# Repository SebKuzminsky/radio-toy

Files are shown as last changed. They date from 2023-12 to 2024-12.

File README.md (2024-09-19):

This is a project inspired by the [Flipper
Zero](https://flipperzero.one/) and the
[ook-remote](https://github.com/SebKuzminsky/ook-remote/tree/master).

The goal is to identify, record, & spoof RF remotes (like the WEN3410
air filter at the hack space).

# Design thoughts

## Radio chip

* [CC1101](https://www.ti.com/product/CC1101).  Lots of modules available.
I have a D-Sun CC1101 and an Ebyte E07-M1101D, they seem about equivalent.
SMA connector, 2x5 male pin header, 2 mounting holes near the antenna.
The D-SUN mounting holes are slightly more convenient.  There's also one
called AS07-M1101S.  For building into a portable product, a module with
solderable through holes instead of the pin header may be preferable.

* [Semtech Sx1276](https://www.semtech.com/products/wireless-rf/lora-connect/sx1276)

* [nRF24L01](https://www.nordicsemi.com/Products/nRF24-series)
"Not recommended for new designs", but it's hard to argue with $1 boards from ebay.
<https://www.sparkfun.com/datasheets/Components/SMD/nRF24L01Pluss_Preliminary_Product_Specification_v1_0.pdf>

## Tethered or untethered?

### Tethered

Connect by USB-C to a laptop or an Android phone (serial terminal or
custom app).

Pros:
* simple to build (no battery & charging)
* simple to talk to (minicom or pySerial)

Cons:
* Conspicuous to have a dongle out and connected.

### Untethered

LiPo battery & USB charging.

LiPo battery options:
* 1x18650: 2200 mAh, 19 mm x 68 mm
* 2x18650: 4400 mAh, 38 mm x 66 mm
* Adafruit Feather battery: 400 mAh, 17.5 mm x 37 mm (fits under a Feather or Pico)

Cons:
* battery & charger
* Bulkier

#### Web UI

The device is a featureless brick, like a USB "power bank".  It has a
USB port (for charging the battery) and an on/off switch.

You connect by Bluetooth or Wifi to a UI on a laptop or phone.  This is
very inconspicuous - you can leave the device in a pocket or backpack
and just play with your phone or laptop.

Or web UI over IP-over-USB,
e.g. <https://github.com/maxnet/pico-webserver>?

I don't know of an RP2040 board with both LiPo and Wifi.  I could
use a Pico W and and external LiPo charger/power supply like this one:
* <https://www.adafruit.com/product/5612>
* <https://shop.pimoroni.com/products/pico-lipo-shim>

BOM:
* Pico W (21 mm wide, 51 mm long)
* CC1101 module of some sort (FIXME)
* Pimoroni Pico LiPo Power Shim (fits under Pico W, solders onto its headers)
* LiPo battery
* 3d printed case

RP2040 board options:
* Pico W
* Seeed Wio RP2040 <https://www.seeedstudio.com/Wio-RP2040-mini-Dev-Board-p-4933.html>
* Arduino Nano RP2040 Connect

# Wiring

```
    Pico GPIO          | Pico Pin | D-Sun CC1101 module
    -------------------+----------+--------------------
    3V3 Out            | 36       | VCC
    GND                | 38       | GND
    -------------------+----------+--------------------
    GPIO 2 (SPI0 SCK)  | 4        | SCK
    GPIO 3 (SPI0 TX)   | 5        | MOSI
                       |          | GDO2
    GPIO 4 (SPI0 RX)   | 6        | MISO
    GPIO 1 (SPI0 CSn)  | 2        | CSN
                       |          | GDO0
    -------------------+----------+--------------------
```

# Firmware

C or Rust?

I really want to use Rust but i'm not sure about software support.

<https://reltech.substack.com/p/getting-started-with-rust-on-a-raspberry>
<https://www.alexdwilson.dev/learning-in-public/running-rust-code-on-raspberry-pi-pico>

<https://github.com/rp-rs/rp2040-project-template>
<https://github.com/rp-rs/rp-hal>
<https://github.com/rp-rs/rp-hal-boards/>

Install rustup and make a personal toolchain.  :-/

```
# curl | sh craziness to install rustup
$ rustup toolchain install stable
$ rustup target add thumbv6m-none-eabi
$ cargo install elf2uf2-rs --locked
$ cargo install flip-link
```

Edit .cargo/config.toml to switch to the elf2uf2-rs runner.

Reset/power-cycle the pico while holding the Bootsel button.  Mount the
pico anywhere.

`$ cargo run --release`

`$ sudo mount /dev/sda1 /mnt -o umask=0 && cargo run; sync; sudo umount /mnt`

`$ cargo doc --open`

# To do

console on usb?

Unknown:

    Embassy?

    Pico SPI?

    Web server/GUI?

        egui?

            <https://github.com/emilk/egui>

            <https://www.egui.rs/#demo>

    Does embassy-net do mdns?  it does igmp but doesnt look like mdns

Working:

    Pico W wifi chip (Infineon CYW43439):

        <https://lib.rs/crates/cyw43>

        <https://github.com/embassy-rs/embassy>

        <https://github.com/embassy-rs/embassy/tree/main/cyw43>

    Pico USB console

        <https://github.com/rp-rs/rp-hal/issues/652#issuecomment-1639975385>

        embassy-usb-logger

# Enclosure

The enclosure holds a Raspberry Pi Pico W, a D-SUN CC1101 module, a
Pimoroni "LiPo SHIM for Pico", and a LiPo 18650 battery.  The FreeCAD
files (and STLs) are in the `enclosure/` directory.

M2 wood screws to hold the radio and the Pico-W to their standoffs.

M2.6 wood screws to hold the two parts of the enclosure together.
Predrill \#42 (2.375 mm).

# CC1101 info & projects

<https://docs.rs/cc1101/latest/cc1101/>

<https://github.com/28757B2/cc1101-driver>

<https://github.com/mengguang/cc1101>

<https://github.com/mcore1976/cc1101-tool>

<https://github.com/LSatan/SmartRC-CC1101-Driver-Lib>

<https://github.com/gusgorman402/RFmoggy>

<https://github.com/ea/srxe_cc1101>

<https://www.printables.com/model/537529-raspberry-pi-pico-rp2040-cc1101-tool-chassis>

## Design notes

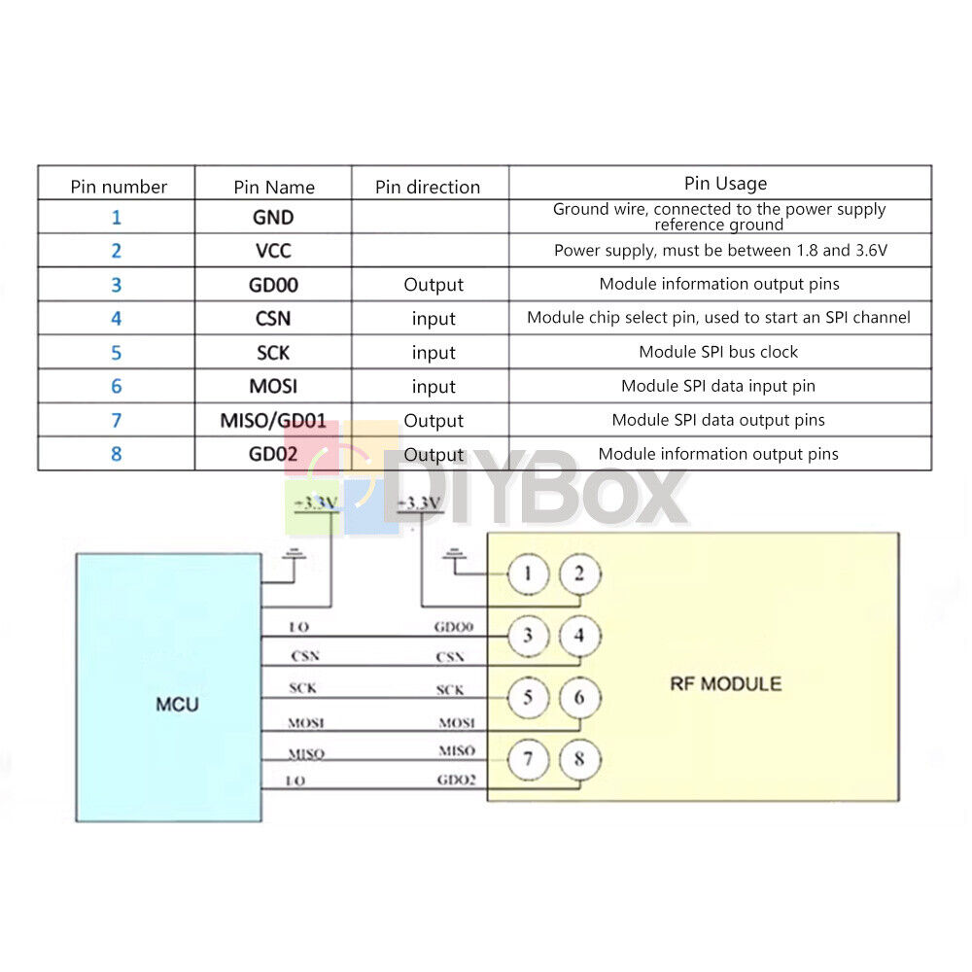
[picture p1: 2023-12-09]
doc/e07-m1101d-pinout.jpg

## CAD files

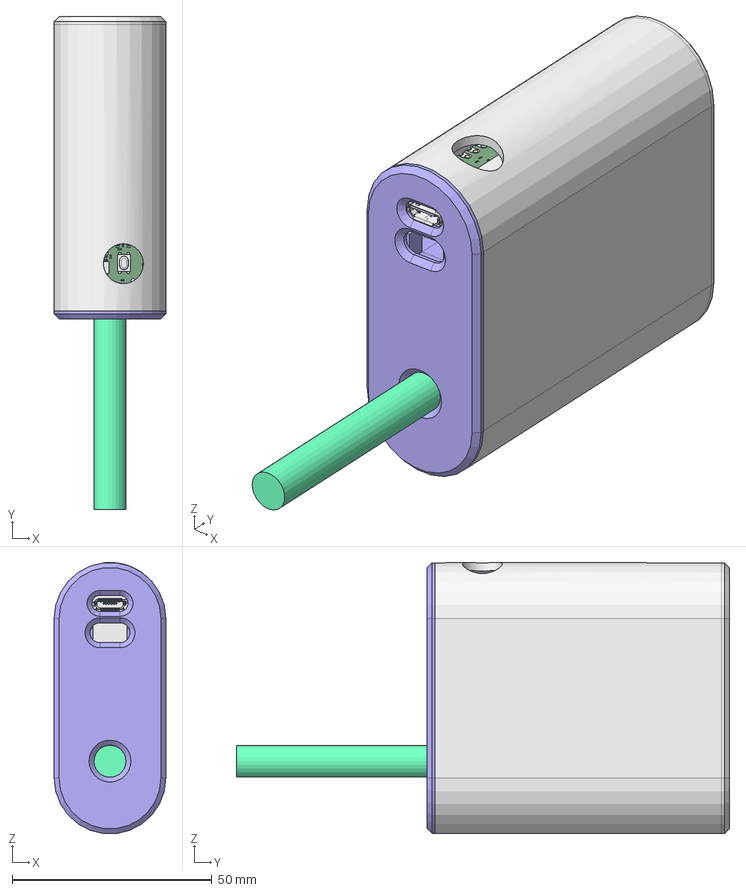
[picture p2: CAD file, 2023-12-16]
enclosure/enclosure.FCStd
28.0 x 123.5 x 67.9 mm
base
SOLDERMASK_TOP
Dielectric
SOLDERMASK_BOTTOM
AVAGO_QSM
AVAGO_QSM001
AVAGO_QSM002
AVAGO_QSM003
AVAGO_QSM004
FCI_10103594-0001LF
FCI_10103594-0001LF001
FCI_10103594-0001LF002
FCI_10103594-0001LF003
FCI_10103594-0001LF004
FCI_10103594-0001LF005
FCI_10103594-0001LF006
RF_SHIELD_PICOW
RPI_RP2040
RT-WDFN-14AL
SOD123FL
SOD123FL001
SOD123FL002
SOD123FL003
TONEPARTS_TP-1221U-K9K5325
XTAL320X250X100
battery
radio
cover

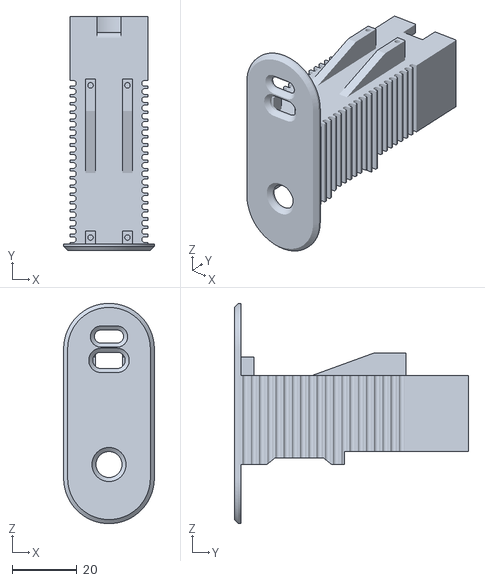
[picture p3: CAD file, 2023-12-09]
enclosure/enclosure-base.stl
28.0 x 72.2 x 68.0

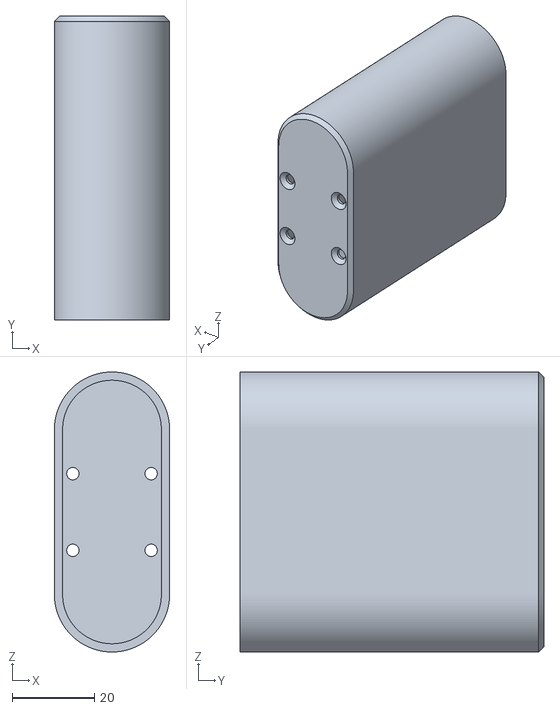
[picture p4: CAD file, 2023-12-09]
enclosure/enclosure-cover.stl
28.0 x 73.8 x 68.0

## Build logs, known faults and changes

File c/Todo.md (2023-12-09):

maybe add all the cc1101's config variables to cc1101_t, have functions
to compute & set them, and a function to flush/sync the config to the chip
(maybe using burst writes)

>64 bytes tx - can the cc1101 signal "low tx fifo" on one of its gpios,
so it can interrupt the rp2040?

What's the smallest rp2040 board with spi & mounting holes?

    Seeed xiao rp2040 is small but doesn't have mounting holes

    Waveshare(?) rp2040-zero is small but doesn't have mounting holes

add spectrum analyser & radio capture/sniffing

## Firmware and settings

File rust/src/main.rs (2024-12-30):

//! This is a firmware for the Raspberry Pi Pico-W that talks to a CC1101
//! radio controller.

#![no_std]
#![no_main]
#![feature(type_alias_impl_trait)]
#![feature(impl_trait_in_assoc_type)]
#![allow(async_fn_in_trait)]

mod command_parser;
mod net_ui;

use cc1101;

use cyw43_pio::PioSpi;
use defmt::*;
use embassy_executor::Spawner;
use embassy_rp::bind_interrupts;
use embassy_rp::clocks::RoscRng;
use embassy_rp::gpio::{Level, Output};
use embassy_rp::peripherals::USB;
use embassy_rp::peripherals::{DMA_CH0, PIO0};
use embassy_rp::pio::Pio;
use embassy_usb_logger::ReceiverHandler;
use rand::RngCore;
use static_cell::StaticCell;
use {defmt_rtt as _, panic_probe as _};

bind_interrupts!(struct Pio0Irqs {
    PIO0_IRQ_0 => embassy_rp::pio::InterruptHandler<PIO0>;
});

bind_interrupts!(struct UsbIrqs {
    USBCTRL_IRQ => embassy_rp::usb::InterruptHandler<USB>;
});

#[embassy_executor::task]
async fn cyw43_task(
    runner: cyw43::Runner<'static, Output<'static>, PioSpi<'static, PIO0, 0, DMA_CH0>>,
) -> ! {
    runner.run().await
}

#[embassy_executor::task]
async fn net_task(mut runner: embassy_net::Runner<'static, cyw43::NetDriver<'static>>) -> ! {
    runner.run().await
}

static USB_SERIAL_COMMAND_CHANNEL: embassy_sync::channel::Channel<
    embassy_sync::blocking_mutex::raw::CriticalSectionRawMutex,
    command_parser::Command,
    100,
> = embassy_sync::channel::Channel::new();

struct USBSerialHandler {
    parser: embassy_sync::mutex::Mutex<
        embassy_sync::blocking_mutex::raw::CriticalSectionRawMutex,
        command_parser::Parser,
    >,
}

impl ReceiverHandler for USBSerialHandler {
    fn new() -> Self {
        Self {
            parser: embassy_sync::mutex::Mutex::new(command_parser::Parser::new()),
        }
    }

    async fn handle_data(&self, data: &[u8]) {
        let mut parser = self.parser.lock().await;
        for b in data {
            if let Some(cmd) = parser.ingest(*b) {
                USB_SERIAL_COMMAND_CHANNEL.send(cmd).await;
            }
        }
    }
}

#[embassy_executor::task]
async fn logger_task(driver: embassy_rp::usb::Driver<'static, USB>) {
    embassy_usb_logger::run!(65535, log::LevelFilter::Info, driver, USBSerialHandler);
}

#[embassy_executor::main]
async fn main(spawner: Spawner) -> ! {
    let p = embassy_rp::init(Default::default());

    let mut rng: RoscRng = RoscRng;

    //
    // Set up logging to USB serial port.
    //

    let usb_driver = embassy_rp::usb::Driver::new(p.USB, UsbIrqs);
    spawner.spawn(logger_task(usb_driver)).unwrap();

    //
    // Set up the Wifi.
    //

    let fw = include_bytes!("../../submodules/embassy/cyw43-firmware/43439A0.bin");
    let clm = include_bytes!("../../submodules/embassy/cyw43-firmware/43439A0_clm.bin");

    // To make flashing faster for development, you may want to flash the firmwares independently
    // at hardcoded addresses, instead of baking them into the program with `include_bytes!`:
    //     probe-rs download 43439A0.bin --format bin --chip RP2040 --base-address 0x10100000
    //     probe-rs download 43439A0_clm.bin --format bin --chip RP2040 --base-address 0x10140000
    //let fw = unsafe { core::slice::from_raw_parts(0x10100000 as *const u8, 230321) };
    //let clm = unsafe { core::slice::from_raw_parts(0x10140000 as *const u8, 4752) };

    let pwr = Output::new(p.PIN_23, Level::Low);
    let cs = Output::new(p.PIN_25, Level::High);
    let mut pio = Pio::new(p.PIO0, Pio0Irqs);
    let spi = PioSpi::new(
        &mut pio.common,
        pio.sm0,
        pio.irq0,
        cs,
        p.PIN_24,
        p.PIN_29,
        p.DMA_CH0,
    );

    static STATE: StaticCell<cyw43::State> = StaticCell::new();
    let state: &mut cyw43::State = STATE.init(cyw43::State::new());
    let (net_device, mut cyw43_control, cyw43_runner) = cyw43::new(state, pwr, spi, fw).await;
    unwrap!(spawner.spawn(cyw43_task(cyw43_runner)));

    cyw43_control.init(clm).await;
    cyw43_control
        .set_power_management(cyw43::PowerManagementMode::PowerSave)
        .await;

    // Use a link-local address for communication without DHCP server
    // FIXME: should pick an unused link-local address here per the protocol
    let net_config = embassy_net::Config::ipv4_static(embassy_net::StaticConfigV4 {
        address: embassy_net::Ipv4Cidr::new(embassy_net::Ipv4Address::new(169, 254, 1, 1), 16),
        dns_servers: heapless::Vec::new(),
        gateway: None,
    });

    // Generate random seed
    let seed: u64 = rng.next_u64();

    // Init network stack
    static STACK_RESOURCES: StaticCell<embassy_net::StackResources<3>> = StaticCell::new();
    let r: &'static mut embassy_net::StackResources<3> =
        STACK_RESOURCES.init(embassy_net::StackResources::new());

    let (stack, runner) = embassy_net::new(net_device, net_config, r, seed);

    unwrap!(spawner.spawn(net_task(runner)));

    cyw43_control.start_ap_open("pico", 5).await;
    //control.start_ap_wpa2("pico", "password", 5).await;

    // Wait a bit to let the serial terminal reconnect.
    embassy_time::Timer::after(embassy_time::Duration::from_millis(1_500)).await;

    //
    // Set up SPI to the CC1101.
    //

    let cc1101_miso = p.PIN_4;
    let cc1101_mosi = p.PIN_3;
    let cc1101_clk = p.PIN_2;
    let cc1101_cs = p.PIN_1;

    let mut spi_config = embassy_rp::spi::Config::default();
    spi_config.frequency = 5_000_000;

    let cc1101_spi_bus = embassy_rp::spi::Spi::new_blocking(
        p.SPI0,
        cc1101_clk,
        cc1101_mosi,
        cc1101_miso,
        spi_config,
    );

    let cc1101_cs = Output::new(cc1101_cs, Level::Low);

    let cc1101_spi_device =
        embedded_hal_bus::spi::ExclusiveDevice::new_no_delay(cc1101_spi_bus, cc1101_cs);

    let mut cc1101 = cc1101::Cc1101::new(cc1101_spi_device).unwrap();

    //
    // Configure the CC1101 for OOK at 433 MHz, 3 kbaud.
    //

    cc1101.reset_chip().unwrap();

    cc1101
        .set_fifo_threshold(true, 0, cc1101::FifoThreshold::TX_61_RX_4)
        .unwrap();

    // PACKET_LENGTH = 4 bytes: FIXME: seems low...
    cc1101
        .0
        .write_register(cc1101::lowlevel::registers::Config::PKTLEN, 0x04)
        .unwrap();

    // PQT = 0: disable preamble quality estimator threshold, not because this application is TX only
    // CRC_AUTOFLUSH = 0: don't flush RX FIFO on CRC failure
    // APPEND_STATUS = 1: append RSSI and LQI to received packets, not used for this application
    // ADR_CHK = 0: no address check
    cc1101
        .0
        .write_register(cc1101::lowlevel::registers::Config::PKTCTRL1, 0x04)
        .unwrap();

    // Packet format:
    // * whitening off
    // * use FIFOs for Rx and Tx
    // * disable CRC calculation on Tx and CRC check on Rx
    // * fixed packet length specified by PKTLEN register
    cc1101
        .0
        .write_register(cc1101::lowlevel::registers::Config::PKTCTRL0, 0x00)
        .unwrap();

    cc1101
        .0
        .write_register(cc1101::lowlevel::registers::Config::ADDR, 0x00)
        .unwrap();

    cc1101
        .0
        .write_register(cc1101::lowlevel::registers::Config::CHANNR, 0x00)
        .unwrap();

    // Set IF (intermediate frequency).
    // FIXME

    cc1101
        .0
        .write_register(cc1101::lowlevel::registers::Config::FSCTRL1, 0x0c)
        .unwrap();

    cc1101
        .0
        .write_register(cc1101::lowlevel::registers::Config::FSCTRL0, 0x00)
        .unwrap();

    // Input bandwidth, ~203 kHz
    cc1101
        .0
        .write_register(cc1101::lowlevel::registers::Config::MDMCFG4, 0x8c)
        .unwrap();

    cc1101.set_data_rate(115_200).unwrap();

    // Set modem to ASK/OOK
    // 0x30: ook, no preamble
    // 0x33: ook, preamble
    cc1101
        .0
        .write_register(cc1101::lowlevel::registers::Config::MDMCFG2, 0x33)
        .unwrap();

    // Disable FEC, 2 preamble bytes
    cc1101
        .0
        .write_register(cc1101::lowlevel::registers::Config::MDMCFG1, 0x22)
        .unwrap();

    cc1101
        .0
        .write_register(cc1101::lowlevel::registers::Config::MDMCFG0, 0xf8)
        .unwrap();

    // Not used for OOK
    cc1101
        .0
        .write_register(cc1101::lowlevel::registers::Config::DEVIATN, 0x62)
        .unwrap();

    // Main Radio Control State Machine Configuration 1:
    // * CCA_MODE=3 ??
    // * RXOFF_MODE=0 (go to IDLE after receiving a packet)
    // * TXOFF_MODE=0 (go to IDLE after transmitting a packet)
    cc1101
        .0
        .write_register(cc1101::lowlevel::registers::Config::MCSM1, 0x30)
        .unwrap();

    // Main Radio Control State Machine Configuration 0:
    // * FS_AUTOCAL=3 (calibrate every 4th time when going from RX or TX to IDLE)
    cc1101
        .0
        .write_register(cc1101::lowlevel::registers::Config::MCSM0, 0x30)
        .unwrap();

    // Configure for OOK per Design Note DN022.
    // * AGCCTRL2 = 0x03 to 0x07
    // * AGCCTRL1 = 0x00
    // * AGCCTRL0 = 0x91 or 0x92

    cc1101
        .0
        .write_register(cc1101::lowlevel::registers::Config::AGCCTRL2, 0x03)
        .unwrap();

    cc1101
        .0
        .write_register(cc1101::lowlevel::registers::Config::AGCCTRL1, 0x00)
        .unwrap();

    cc1101
        .0
        .write_register(cc1101::lowlevel::registers::Config::AGCCTRL0, 0x91)
        .unwrap();

    cc1101
        .0
        .write_register(cc1101::lowlevel::registers::Config::FSCAL3, 0xea)
        .unwrap();

    cc1101
        .0
        .write_register(cc1101::lowlevel::registers::Config::FSCAL2, 0x2a)
        .unwrap();

    cc1101
        .0
        .write_register(cc1101::lowlevel::registers::Config::FSCAL1, 0x00)
        .unwrap();

    cc1101
        .0
        .write_register(cc1101::lowlevel::registers::Config::FSCAL0, 0x1f)
        .unwrap();

    // FREND1:
    //     RX filter bandwidth > 101 kHz, FREND1 = 0xB6
    //     RX filter bandwidth ≤ 101 kHz, FREND1 = 0x56
    // TEST2:
    //     RX filter bandwidth > 325 kHz, TEST2 = 0x88
    //     RX filter bandwidth ≤ 325 kHz, TEST2 = 0x81
    // TEST1:
    //     RX filter bandwidth > 325 kHz, TEST1 = 0x31
    //     RX filter bandwidth ≤ 325 kHz, TEST1 = 0x35

    cc1101
        .0
        .write_register(cc1101::lowlevel::registers::Config::FREND1, 0xb6)
        .unwrap();
    cc1101
        .0
        .write_register(cc1101::lowlevel::registers::Config::FREND0, 0x11)
        .unwrap();

    cc1101
        .0
        .write_register(cc1101::lowlevel::registers::Config::TEST2, 0x88)
        .unwrap();

    cc1101
        .0
        .write_register(cc1101::lowlevel::registers::Config::TEST1, 0x31)
        .unwrap();

    cc1101
        .0
        .write_register(cc1101::lowlevel::registers::Config::TEST0, 0x09)
        .unwrap();

    cc1101
        .0
        .write_register(cc1101::lowlevel::registers::Config::FOCCFG, 0x1d)
        .unwrap();

    cc1101
        .0
        .write_register(cc1101::lowlevel::registers::Config::BSCFG, 0x1c)
        .unwrap();

    let patable_values: [u8; 2] = [0x00, 0xc6];
    cc1101.write_patable(&patable_values).unwrap();

    // Flush the TX FIFO
    cc1101
        .0
        .write_cmd_strobe(cc1101::lowlevel::registers::Command::SFTX)
        .unwrap();

    // Calibrate the frequency synthesizer.
    cc1101.set_radio_mode(cc1101::RadioMode::Calibrate).unwrap();

    // Ok, now we're ready.

    // And now we can use it!

    static NET_COMMAND_CHANNEL: embassy_sync::channel::Channel<
        embassy_sync::blocking_mutex::raw::CriticalSectionRawMutex,
        command_parser::Command,
        100,
    > = embassy_sync::channel::Channel::new();

    spawner
        .spawn(net_ui::net_ui_task(stack, &NET_COMMAND_CHANNEL))
        .unwrap();

    loop {
        let command: command_parser::Command = match embassy_futures::select::select(
            NET_COMMAND_CHANNEL.receiver().receive(),
            USB_SERIAL_COMMAND_CHANNEL.receiver().receive(),
        )
        .await
        {
            embassy_futures::select::Either::First(command) => command,
            embassy_futures::select::Either::Second(command) => command,
        };

        match command {
            command_parser::Command::Ping => {
                log::info!("Pong");
            }

            command_parser::Command::TxPreambleBytes(num_preamble_bytes) => {
                log::info!("tx-preamble-bytes {}", num_preamble_bytes);

                let r = cc1101
                    .0
                    .read_register(cc1101::lowlevel::registers::Config::MDMCFG1)
                    .unwrap();
                let mdmcfg1 = cc1101::lowlevel::registers::MDMCFG1(r);
                let mut mdmcfg1 = mdmcfg1.modify();

                // Setting | Number of preamble bytes
                // 0 (000) | 2
                // 1 (001) | 3
                // 2 (010) | 4
                // 3 (011) | 6
                // 4 (100) | 8
                // 5 (101) | 12
                // 6 (110) | 16
                // 7 (111) | 24

                let num_preamble_field = match num_preamble_bytes {
                    x if x <= 2 => 0,
                    x if x == 3 => 1,
                    x if x == 4 => 2,
                    x if x <= 6 => 3,
                    x if x <= 8 => 4,
                    x if x <= 12 => 5,
                    x if x <= 16 => 6,
                    x if x <= 24 => 7,
                    _ => 7,
                };
                mdmcfg1.num_preamble(num_preamble_field);

                cc1101
                    .0
                    .write_register(cc1101::lowlevel::registers::Config::MDMCFG1, mdmcfg1.bits())
                    .unwrap();
            }

            command_parser::Command::SyncWordMSB(n) => {
                log::info!("sync-word-msb {}", n);
                let sync1 = cc1101::lowlevel::registers::SYNC1(n);
                cc1101
                    .0
                    .write_register(cc1101::lowlevel::registers::Config::SYNC1, sync1.bits())
                    .unwrap();
            }

            command_parser::Command::SyncWordLSB(n) => {
                log::info!("sync-word-lsb {}", n);
                let sync0 = cc1101::lowlevel::registers::SYNC0(n);
                cc1101
                    .0
                    .write_register(cc1101::lowlevel::registers::Config::SYNC0, sync0.bits())
                    .unwrap();
            }

            command_parser::Command::SyncMode(n) => {
                log::info!("sync-mode {}", n);

                let r = cc1101
                    .0
                    .read_register(cc1101::lowlevel::registers::Config::MDMCFG2)
                    .unwrap();
                let mdmcfg2 = cc1101::lowlevel::registers::MDMCFG2(r);
                let mut mdmcfg2 = mdmcfg2.modify();
                mdmcfg2.sync_mode(n & 0x7);

                cc1101
                    .0
                    .write_register(cc1101::lowlevel::registers::Config::MDMCFG2, mdmcfg2.bits())
                    .unwrap();
            }

            command_parser::Command::Frequency(n) => {
                log::info!("frequency {}", n);
                cc1101.set_frequency(n as u64).unwrap();
                cc1101.set_radio_mode(cc1101::RadioMode::Calibrate).unwrap();
            }

            command_parser::Command::Baud(n) => {
                log::info!("baud {}", n);
                cc1101.set_data_rate(n as u64).unwrap();
            }

            command_parser::Command::PacketLength(n) => {
                log::info!("packet length {}", n);
                cc1101
                    .set_packet_length(cc1101::PacketLength::Fixed(n))
                    .unwrap();
            }

            command_parser::Command::Idle => {
                log::info!("idle");
                cc1101.set_radio_mode(cc1101::RadioMode::Idle).unwrap();
            }

            command_parser::Command::TxFifo(byte) => {
                log::info!("tx-fifo 0x{:02x}", byte);
                cc1101
                    .0
                    .write_register(cc1101::lowlevel::registers::MultiByte::FIFO, byte)
                    .unwrap();
            }

            command_parser::Command::DoTx => {
                log::info!("do-tx");
                cc1101.enable_tx().unwrap();
            }
        }
    }
}

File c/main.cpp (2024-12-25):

#include <cstdio>
#include <ctype.h>
#include <math.h>
#include <stdlib.h>
#include <string.h>

#include "pico/stdlib.h"
#include "hardware/clocks.h"
#include "hardware/spi.h"

#include "cc1101.h"


// Rising edge on this GPIO indicates beginning of a transmission,
// used to trigger a scope for debugging.
uint const debug_gpio = 1;


bool debug_flag = true;

#define debug(fmt, ...) \
    do { if (debug_flag) printf(fmt, ## __VA_ARGS__); } while (0)


// Process command lines received from the computer via USB serial.
// Command lines consist of one or more space-delimited tokens.
void process_input_line(cc1101_t * cc1101, char * in) {
    debug("processing line '%s'\n", in);

    char const * delim = " \t";
    char * cmd = strtok(in, delim);

    if (strcasecmp("tx", cmd) == 0) {
        debug("got 'tx'\n");
        uint32_t data;
        int r;
        char * token = strtok(NULL, delim);
        r = sscanf(token, "%lx", &data);
        if (r != 1) {
            printf("failed to parse value from '%s'\n", token);
            return;
        }
        debug("tx 0x%08lx\n", data);

        cc1101_write_register(cc1101, FIFO, 0xff & (data >> 24));
        cc1101_write_register(cc1101, FIFO, 0xff & (data >> 16));
        cc1101_write_register(cc1101, FIFO, 0xff & (data >> 8));
        cc1101_write_register(cc1101, FIFO, 0xff & data);

        // Start the TX.
        cc1101_command_strobe(cc1101, STX);

        cc1101_wait_for_idle(cc1101);

    } else if (strcasecmp("tx-fifo", cmd) == 0) {
        debug("got 'tx-fifo'\n");
        uint8_t status0, status1;
        int data;
        int r;
        char * token = strtok(NULL, delim);
        r = sscanf(token, "%x", &data);
        if (r != 1) {
            printf("failed to parse value from '%s'\n", token);
            return;
        }
        debug("tx-fifo 0x%02x\n", data);

        cc1101_write_register(cc1101, FIFO, data, &status0, &status1);
        debug("    status0: 0x%02x\n", status0);
        debug("    status1: 0x%02x\n", status1);

        uint8_t value;
        cc1101_txbytes(cc1101, &value);
        printf("%d bytes in tx fifo%s\n", 0x7f & value, 0x80 & value ? " (underflow!)" : "");

    } else if (strcasecmp("do-tx", cmd) == 0) {
        debug("got 'do-tx'\n");
        // Start the TX.
        cc1101_command_strobe(cc1101, STX);
        cc1101_wait_for_idle(cc1101);

    } else if (strcasecmp("txbytes", cmd) == 0) {
        debug("got 'txbytes'\n");
        uint8_t value;
        cc1101_txbytes(cc1101, &value);
        printf("%d bytes in tx fifo%s\n", 0x7f & value, 0x80 & value ? " (underflow!)" : "");

    } else if (strcasecmp("rxbytes", cmd) == 0) {
        debug("got 'rxbytes'\n");
        uint8_t value;
        cc1101_rxbytes(cc1101, &value);
        printf("%d bytes in rx fifo%s\n", 0x7f & value, 0x80 & value ? " (overflow!)" : "");

    } else if (strcasecmp("idle", cmd) == 0) {
        debug("got 'idle'\n");
        cc1101_idle(cc1101);

#if 0
        gpio_put(debug_gpio, 1);
        ook_send(data);
        gpio_put(debug_gpio, 0);
#endif

#if 0
    } else if (strncasecmp("us-per-bit", in, 10) == 0) {
        uint us_per_bit = 0;
        int r;
        r = sscanf(&in[10], "%u", &us_per_bit);
        if (r != 1) {
            printf("failed to parse '%s'\n", in);
            return;
        }
        debug("us-per-bit %u\n", us_per_bit);
        ook_start(us_per_bit);
#endif

    } else if (strcasecmp("tx-preamble-bytes", cmd) == 0) {
        debug("got tx-preamble-bytes\n");
        uint32_t num_preamble_bytes;
        int r;
        char * token = strtok(NULL, delim);
        r = sscanf(token, "%lu", &num_preamble_bytes);
        if (r != 1) {
            printf("failed to parse value from '%s', r=%d\n", token, r);
            return;
        }
        debug("tx-preamble-bytes %lu\n", num_preamble_bytes);
        cc1101_set_tx_preamble_bytes(cc1101, num_preamble_bytes);

    } else if (strcasecmp("baud", cmd) == 0) {
        debug("got baud\n");
        uint32_t baud;
        int r;
        char * token = strtok(NULL, delim);
        r = sscanf(token, "%lu", &baud);
        if (r != 1) {
            printf("failed to parse value from '%s'\n", token);
            return;
        }
        debug("baud %lu\n", baud);
        cc1101_set_baudrate(cc1101, baud);

    } else if (strcasecmp("freq", cmd) == 0) {
        debug("got freq\n");
        uint32_t freq_hz;
        int r;
        char * token = strtok(NULL, delim);
        r = sscanf(token, "%lu", &freq_hz);
        if (r != 1) {
            printf("failed to parse value from '%s'\n", token);
            return;
        }
        debug("freq %lu\n", freq_hz);
        cc1101_set_base_frequency(cc1101, freq_hz);

    } else if (strcasecmp("sync-word-msb", cmd) == 0) {
        debug("got sync-word-msb\n");
        int value;
        int r;
        char * token = strtok(NULL, delim);
        r = sscanf(token, "%x", &value);
        if (r != 1) {
            printf("failed to parse value from '%s'\n", token);
            return;
        }
        debug("msb 0x%02x\n", value);
        cc1101_set_sync_word_msb(cc1101, value);

    } else if (strcasecmp("sync-word-lsb", cmd) == 0) {
        debug("got sync-word-lsb\n");
        int value;
        int r;
        char * token = strtok(NULL, delim);
        r = sscanf(token, "%x", &value);
        if (r != 1) {
            printf("failed to parse value from '%s'\n", token);
            return;
        }
        debug("lsb 0x%02x\n", value);
        cc1101_set_sync_word_lsb(cc1101, value);

    } else if (strcasecmp("sync-mode", cmd) == 0) {
        debug("got sync-mode\n");
        int value;
        int r;
        char * token = strtok(NULL, delim);
        r = sscanf(token, "%d", &value);
        if (r != 1) {
            printf("failed to parse value from '%s'\n", token);
            return;
        }
        debug("sync-mode %d\n", value);
        cc1101_set_sync_mode(cc1101, value);

    } else if (strcasecmp("pktlen", cmd) == 0) {
        debug("got pktlen\n");
        int value;
        int r;
        char * token = strtok(NULL, delim);
        r = sscanf(token, "%d", &value);
        if (r != 1) {
            printf("failed to parse value from '%s'\n", token);
            return;
        }
        debug("pktlen %d\n", value);
        cc1101_set_packet_length(cc1101, value);

    } else if (strcasecmp("debug", cmd) == 0) {
        debug("got debug\n");
        debug_flag = !debug_flag;
        cc1101_set_debug(cc1101, debug_flag);
        debug("debug is %d\n", debug_flag);

    } else {
        printf("unknown input '%s'\n", in);
    }
}
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

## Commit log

2023-11-21 wire up a cc1101, read all the registers
2023-11-22 better error handling & debug logging
    [main.cpp]
2023-12-09 fixup parse error messages in process_input_line()
    [main.cpp]
2023-12-09 add a couple more functions & matching serial commands
2023-12-09 make it easier to build for different pico boards
2023-12-09 switch to spi0, so it works on seeed xiao rp2040 too
2023-12-09 add the Pico W datasheet
2023-12-09 start an enclosure
    [enclosure-base.stl, enclosure.FCStd]
2023-12-09 improve enclosure some
    [enclosure-base.stl, enclosure.FCStd]
2023-12-09 add mounting holes for the case cover
    [enclosure-base.stl, enclosure.FCStd]
2023-12-09 enclosure: better mounting-hole-rail sculpting for the radio board
    This make more room for the components on the underside of the board,
    hopefully enough.
    [enclosure-base.stl, enclosure.FCStd]
2023-12-09 enclosure: better mounting hole rails for the pico-w
    [enclosure-base.stl, enclosure.FCStd]
2023-12-09 enclosure: larger wire guides, these should fit AWG 22
    [enclosure-base.stl, enclosure.FCStd]
2023-12-09 enclosure: make it wider, so there's more room for wires (awg 22)
    [enclosure-base.stl, enclosure.FCStd]
2023-12-09 enclosure: add a cover
    [enclosure-base.stl, enclosure-cover.stl, enclosure.FCStd]
2023-12-09 enclosure: larger m2.5 threaded holes
    [enclosure-base.stl, enclosure-cover.stl, enclosure.FCStd]
2023-12-09 some notes on assembling the enclosure
2023-12-09 enclosure: minor fixes
    [enclosure-base.stl, enclosure-cover.stl, enclosure.FCStd]
2023-12-09 use elf2uf2 runner
    This finds a mounted Pico and copies the uf2 firmware to it.
2023-12-09 use embassy, build Pico W "wifi blinky" example
    This is from <https://github.com/embassy-rs/embassy/>,
    `examples/rp/src/bin/wifi_blinky.rs`.
2023-12-16 enclosure: git ignore the freecad backup file
2023-12-16 enclosure: add a window to poke the bootsel button
    [enclosure.FCStd]
2023-12-16 switch cc1101 submodule to my repo
2023-12-16 hardcode transmitting a packet, this controls the air filter
2023-12-16 fix a copy/paste error in the header comment
    [main.rs]
2023-12-23 move rust submodules out of the rust project dir
    Having the submodules in the old place confused cargo and prevented me
    from building the submodules by themselves.
    [main.rs]
2024-12-24 Dockerfile.pico: make sure everything's installed
    Belts & suspenders.
2024-12-24 cmake: include pico-sdk in the recommended way
2024-12-24 Dockerfile.pico: install all of picotool
2024-12-24 cmake: require the latest pico-sdk
2024-12-25 c firmware: clocks_init() is not needed with pico-sdk 2.1.0
2024-12-29 write to FIFO correctly (should switch to burst)
    [main.rs]
2024-12-29 couple of minor cleanups
2024-12-29 simplify frequency-setting and calibration
2024-12-29 better writing to the tcp socket
2024-12-30 implement the last of the missing commands
    [main.rs]
2024-12-30 don't bother with the ook-remote script, just cat the commands
    This can go in the USB serial port or into the TCP socket, e.g:
    `$ nc -N 169.254.1.1 1234 < wen3410-on.ook`
2024-12-30 reset the cc1101 at startup
    [main.rs]
2024-12-30 calibrate the radio after changing frequency
